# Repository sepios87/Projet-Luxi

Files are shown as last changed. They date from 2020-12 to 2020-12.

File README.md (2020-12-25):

# Projet-Luxi 💡

https://youtu.be/BHOKpEK1EPY

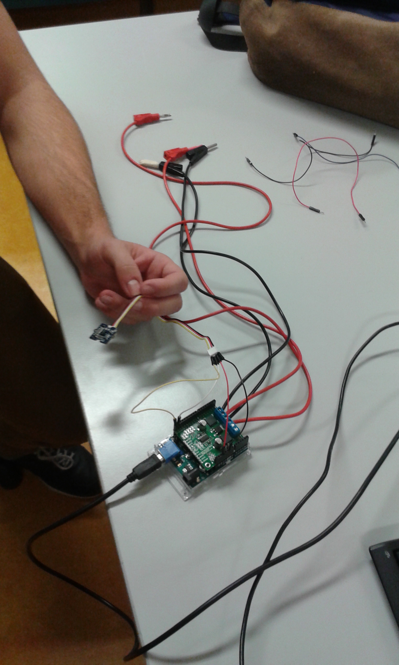
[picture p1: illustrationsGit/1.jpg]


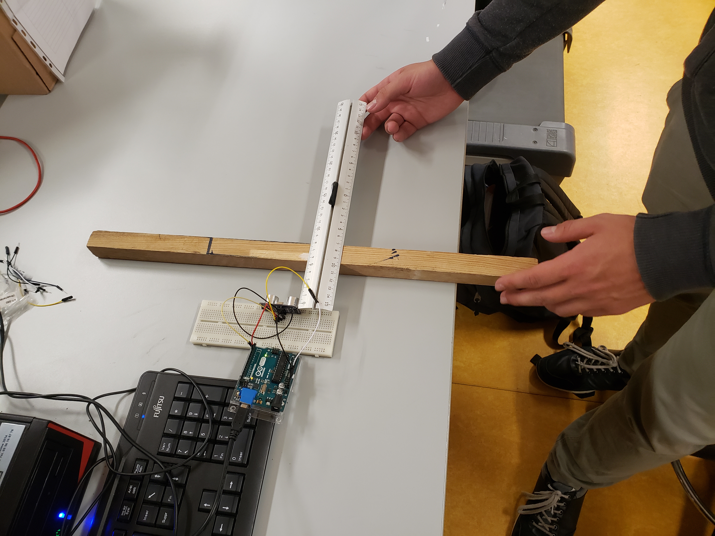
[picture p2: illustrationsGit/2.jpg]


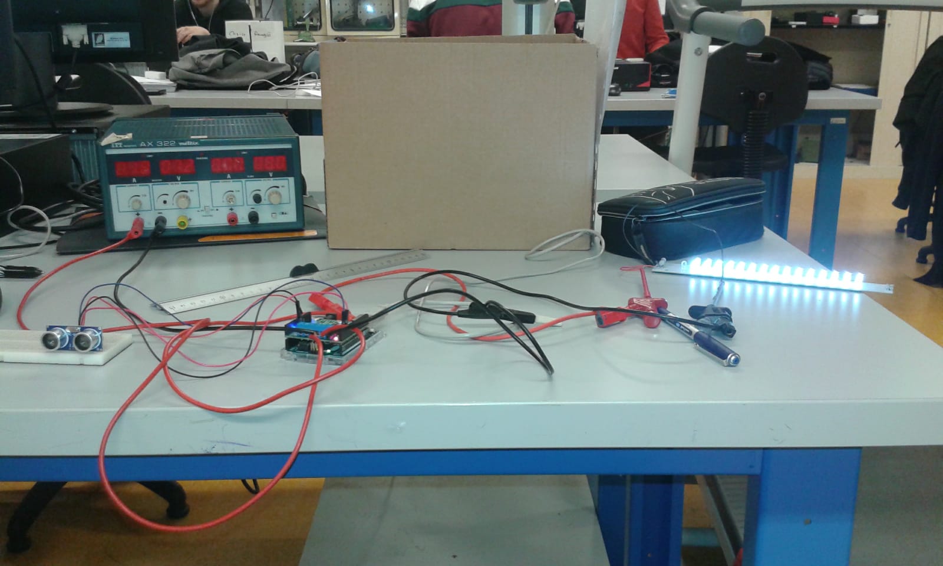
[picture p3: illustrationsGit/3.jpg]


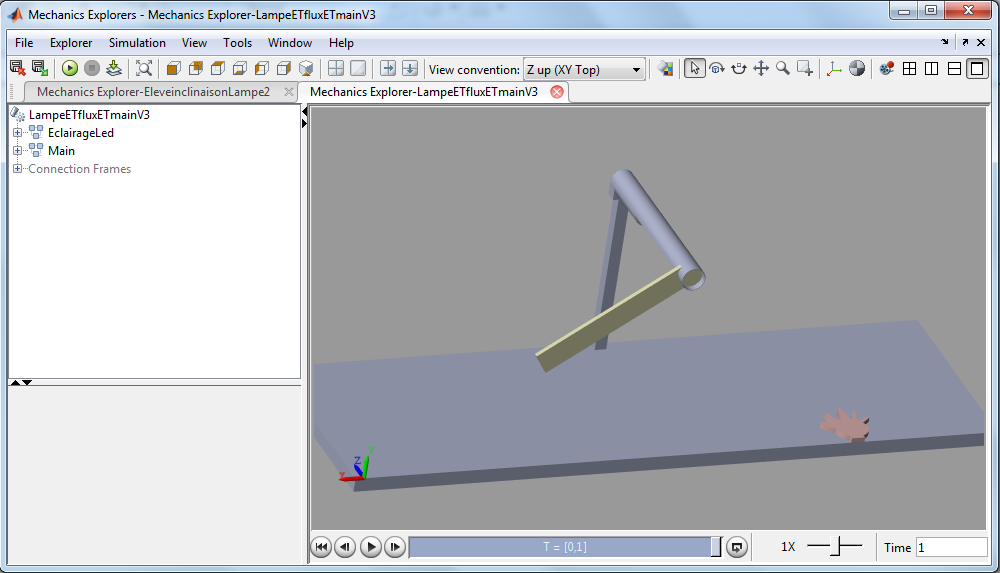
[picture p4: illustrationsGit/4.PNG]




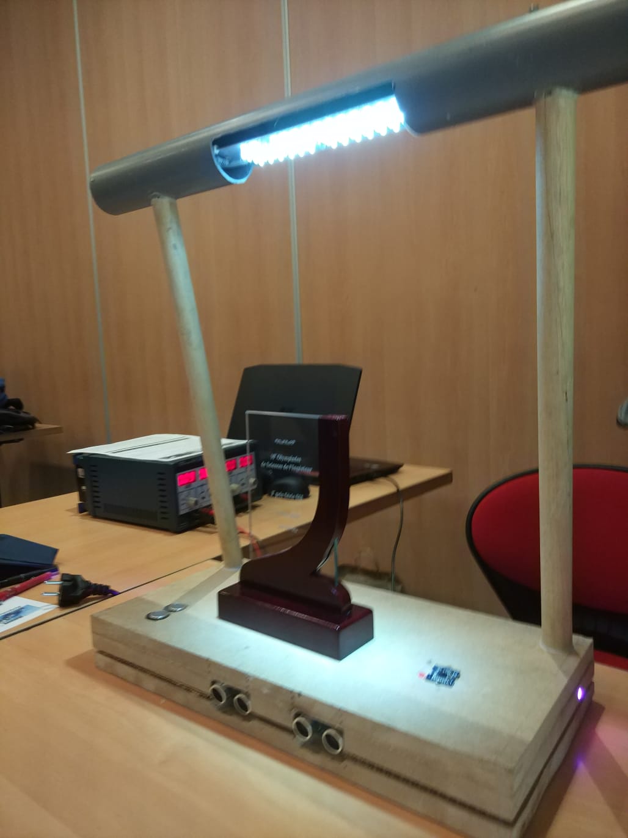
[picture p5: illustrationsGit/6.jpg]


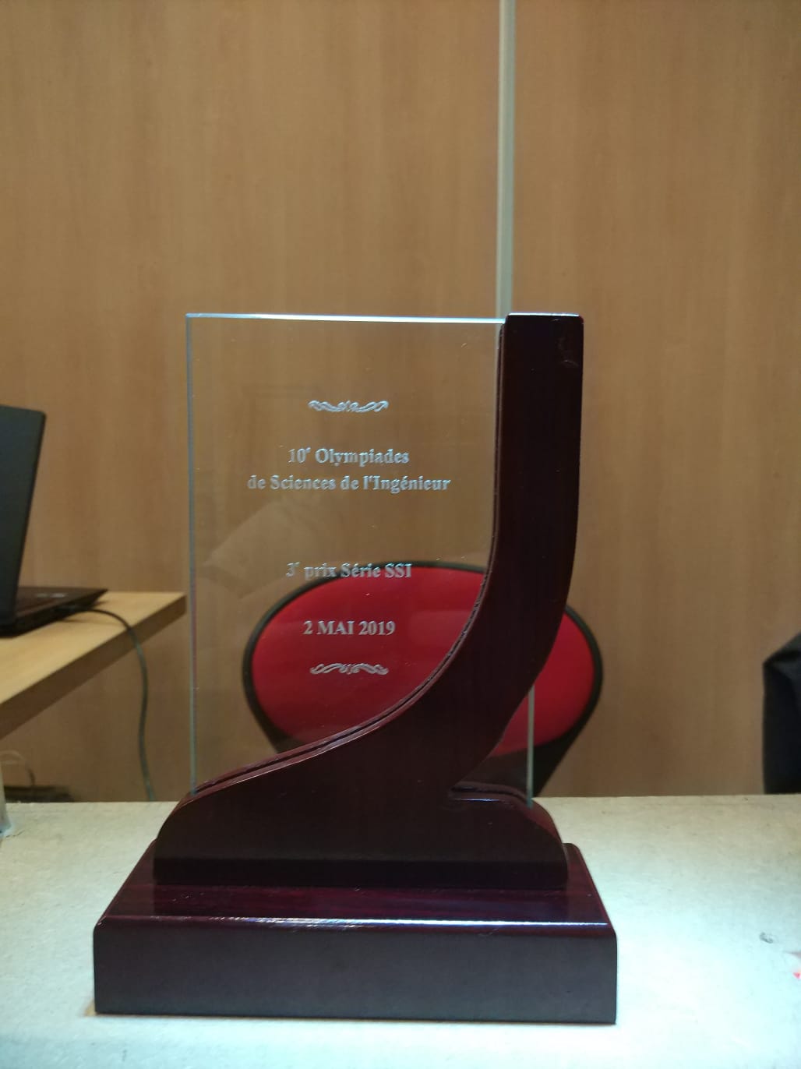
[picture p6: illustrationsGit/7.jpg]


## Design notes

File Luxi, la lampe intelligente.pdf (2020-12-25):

# Luxi, la lampe intelligente

Détection des mouvements
Candidat C

3-8

# Sommaire

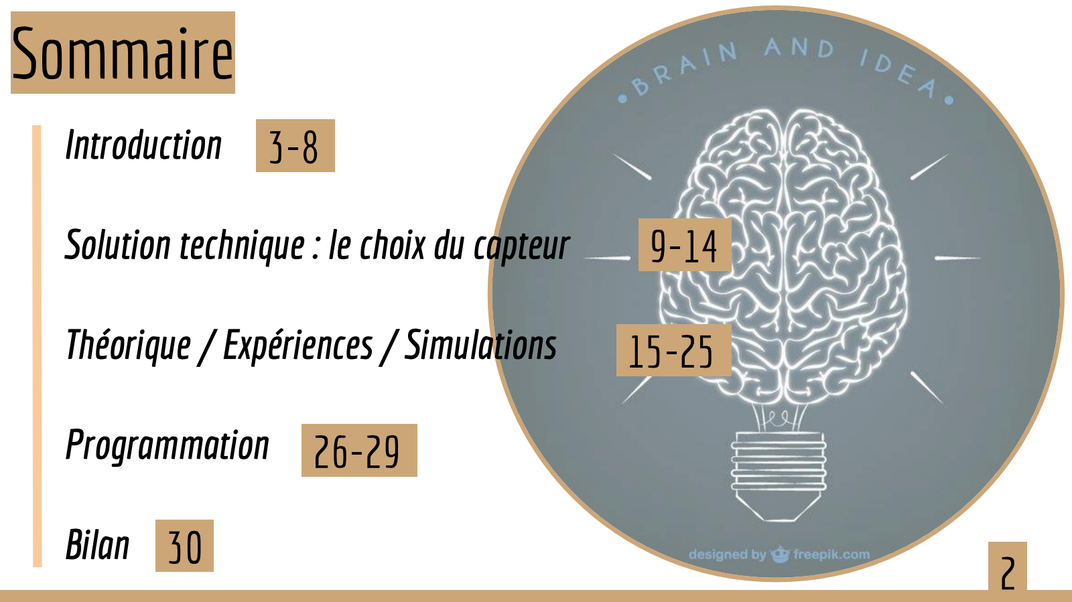
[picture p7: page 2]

2

Introduction

Solution technique : le choix du capteur

Théorique / Expériences / Simulations

Programmation

Bilan

9-14

15-25

26-29

30

# Luxi : la genèse

3

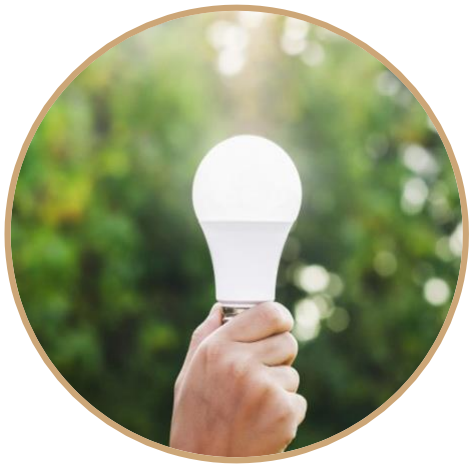
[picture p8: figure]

# Libérer l’utilisateur de la gestion de la lumière

# Pourquoi Luxi ?

4

# Des conditions toujours optimales de lumière Stimuler les activités de l’utilisateur

# Contraintes SysML

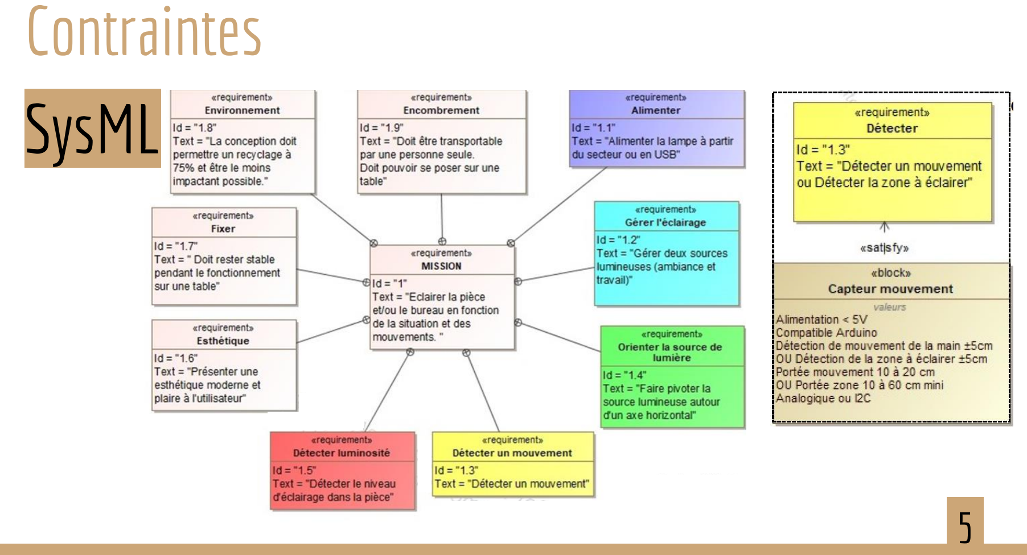
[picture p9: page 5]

5

# ANALYSE DU BESOIN

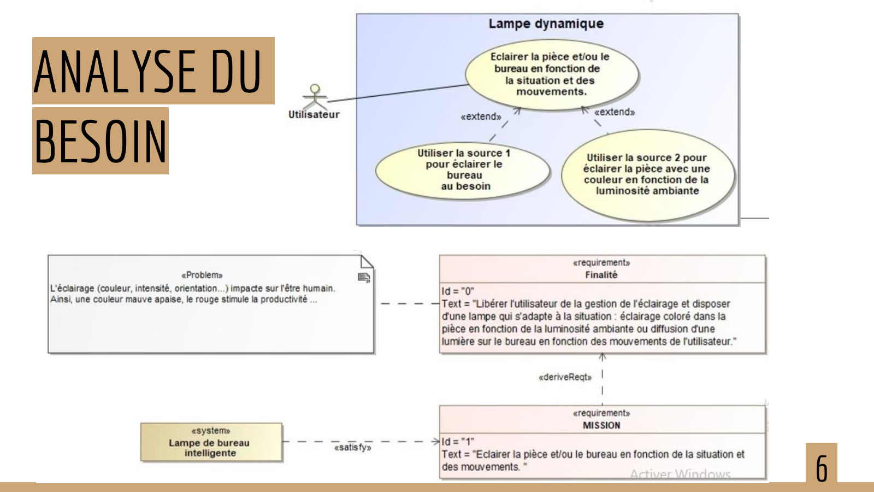
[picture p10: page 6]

6

# Chaîne d’information et d’énergie

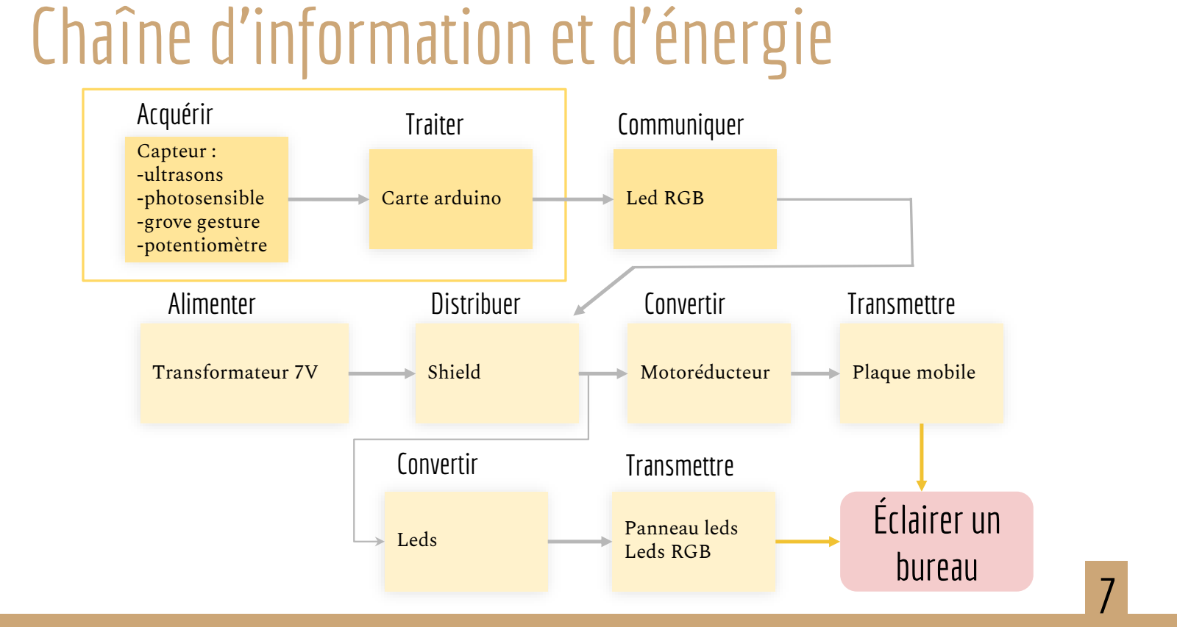
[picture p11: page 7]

Capteur :
-ultrasons
-photosensible
-grove gesture
-potentiomètre

Shield

Leds

Transformateur 7V | Motoréducteur
Carte arduino | Led RGB

Panneau leds
Leds RGB

Acquérir

Alimenter

Traiter | Communiquer
Distribuer | Convertir

Plaque mobile

Transmettre

Convertir | Transmettre
Éclairer un
bureau 7

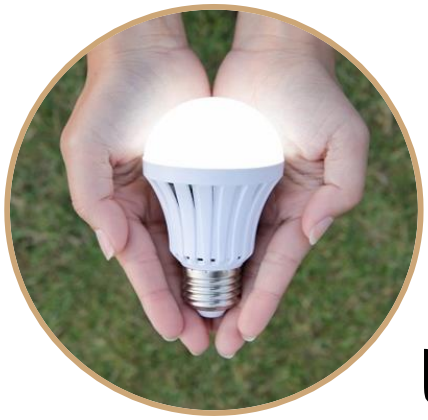
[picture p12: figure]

Utiliser un ordinateur | Ecrire | Lire

# Utilisateur

120cm

Bureau | 80cm

8

### (INRS)

# Mes missions pour ce projet

### Récupérer une distance pour orienter le flux lumineux

### Connaître les actions de l’utilisateur pour adapter les couleurs

### Faire varier l’intensité lumineuse en manuel

9

# Solution technique : le choix du capteur

10

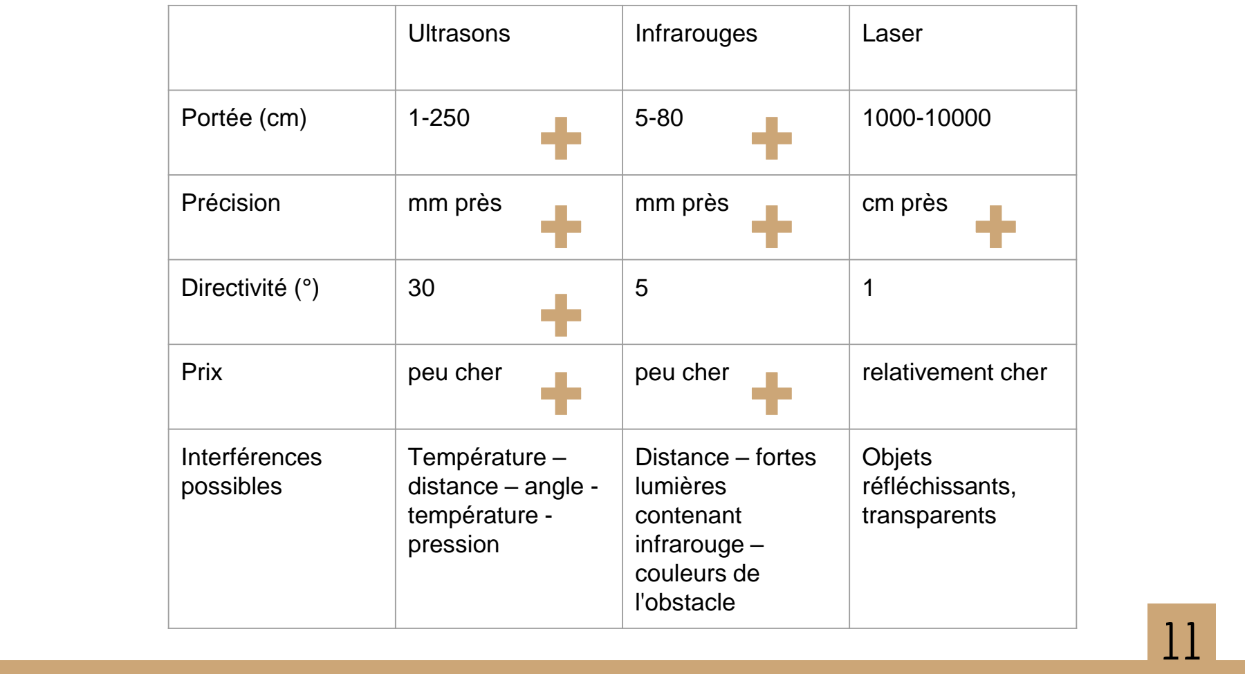
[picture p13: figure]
Ultrasons; Infrarouges; Laser; Portée (cm); Précision; mm près; cm près; Directivité (°); Interférences possibles; Température – distance – angle - température - pression; Distance – fortes lumières contenant infrarouge – couleurs de l'obstacle; Objets réfléchissants, transparents

Prix | peu cher | peu cher | relativement cher

Ultrasons

Sons Audibles

Infrasons

Fréquence d’émission du
capteur

# Inconvénient

Sensibilité de certains
chiens à cette
fréquence d’environ
40KHz
12

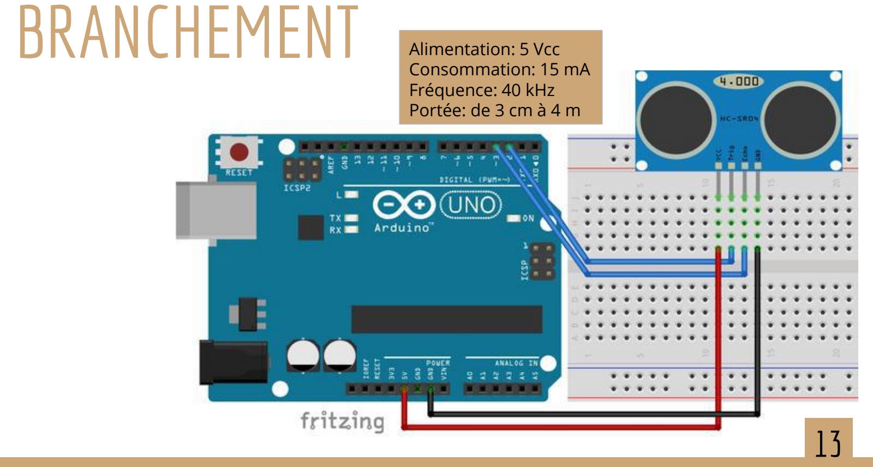
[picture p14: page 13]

BRANCHEMENT Alimentation: 5 Vcc

Consommation: 15 mA
Fréquence: 40 kHz
Portée: de 3 cm à 4 m

13

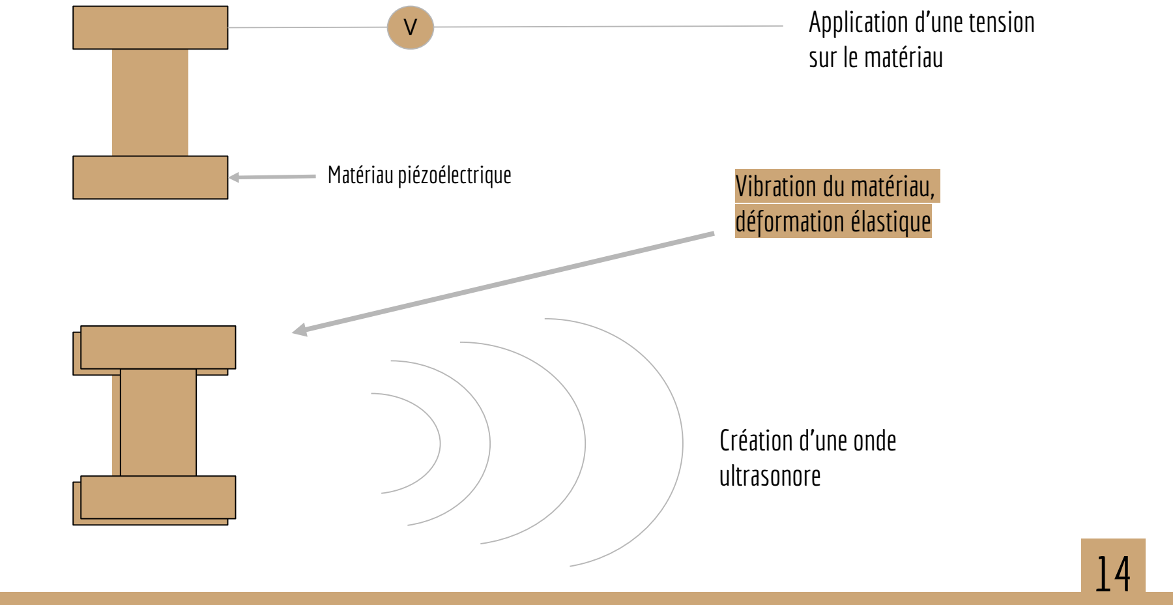
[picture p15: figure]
Application d'une tension sur le matériau; Matériau piézoélectrique; Vibration du matériau,; déformation élastique; Création d'une onde ultrasonore
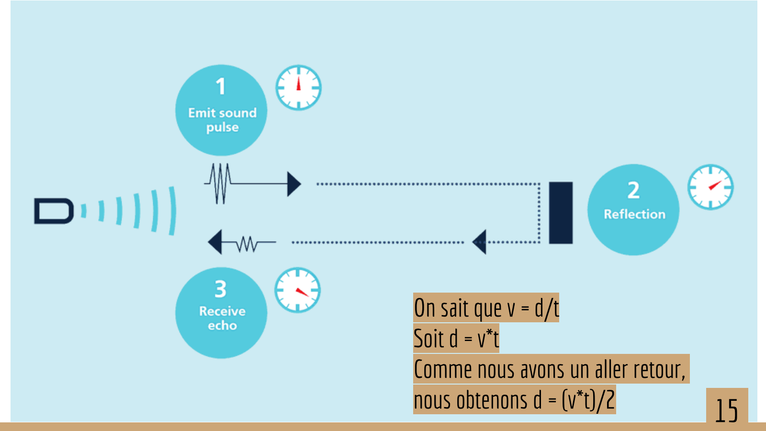
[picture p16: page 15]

On sait que v = d/t
Soit d = v*t
Comme nous avons un aller retour,
nous obtenons d = (v*t)/2 | 15

# Théorie, expériences et simulations

16

# racine(1,4*R*T)

V : vitesse du son ou de l'ultrason dans l'air (m/s)

T : température de l'air (K)

R : constante spécifique de l'air ( 281,8 Joules/Kg )

1,4 : masse volumique de l'air

V = racine(1,4*(18+273,15)*281,8) = 338,54m/s

V =

17

* température idéale d’une chambre 18°

*

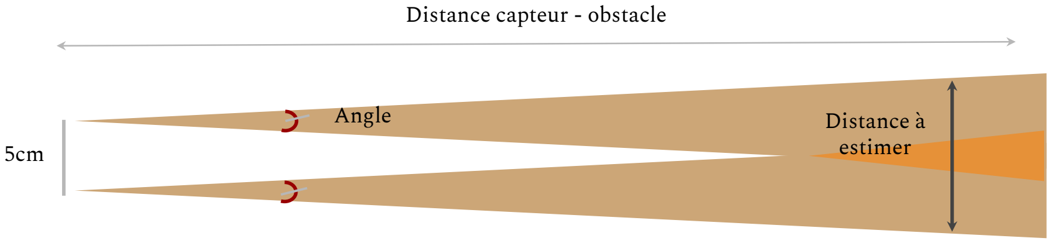
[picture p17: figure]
Angle; Distance capteur - obstacle; Distance à estimer

2d * tan(angle/2) + 5

(d.tan(angle/2).4) - (2⋅(d-(2.5/tan(angle/2))*tan(angle/2)))

Formule pour la distance cherchée pour les deux cônes avec ajustement lors du croisement

## THÉORIQUE (principe général)

(d.tan(angle/2).4) - (2d*tan(angle/2)-5)

THÉORIQUE
Angle/ Distance | 10 | 20 | 30 | 40 | 50 | 60 | 80 | 100 | 200
15 | 7.5 | 9.9 | 12.4 | 14.1 | 17.2 | 19.7 | 24.6 | 29.5 | 54.1

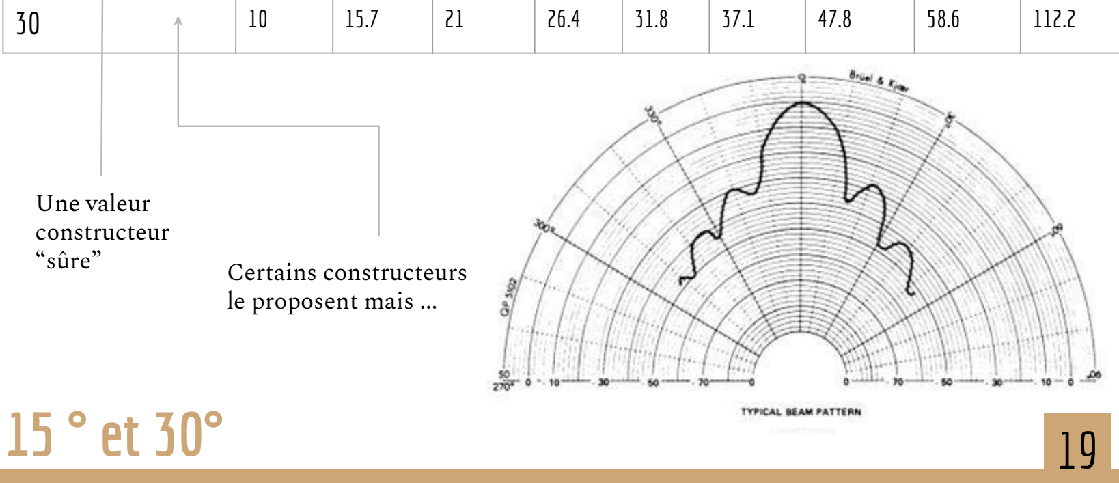
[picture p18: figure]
Une valeur constructeur; “sûre”; Certains constructeurs; le proposent mais ...
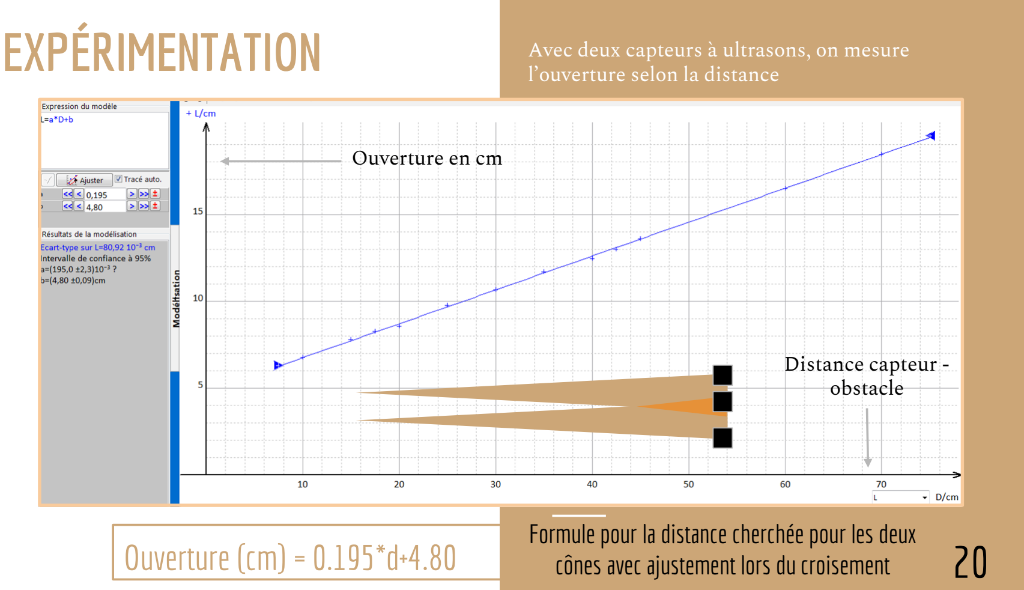
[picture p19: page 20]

EXPÉRIMENTATION | Avec deux capteurs à ultrasons, on mesure l’ouverture selon la distance

Ouverture en cm

Distance capteur -
obstacle
Ouverture (cm) = 0.195*d+4.80 | 20

Formule pour la distance cherchée pour les deux cônes avec ajustement lors du croisement

E
C
A
R
T

Ecarts “moyens et extrêmes” On peut réaliser un écart pour une valeur utilisateur moyenne (30cm) et maximale (70cm)

Théorique

2*30*tan(15/2)+5 = 12.89cm 2*70*tan(15/2)+5 = 23.43cm

Expérimentale

0.195*30+4.80 = 10.65cm
0.195*60+4.80 = 18.45cm

Ecart relatif (%) : (|théorique-

expérimentale|*100)/théorique
E30cm = 17.37%
E60cm = 21.25%
21

>10%

Expérimentale : Ouverture (cm) = 0.195*d+4.80

Théorique : 2d*tan(angle/2)+5

E
C
A
R
T

# Plus proche de 11° que de 15° ?

## Théorique

2*30*tan(11/2)+5 = 10.77cm 2*70*tan(11/2)+5 = 18.48cm

## Expérimentale

0.195*30+4.80 = 10.65cm
0.195*70+4.80 = 18.45cm

Ecart relatif (%) : (|théorique-

expérimentale|*100)/théorique

E30cm = 1.11%
E60cm = 0.16%
22

N °2

<5%

Le

# meilleur

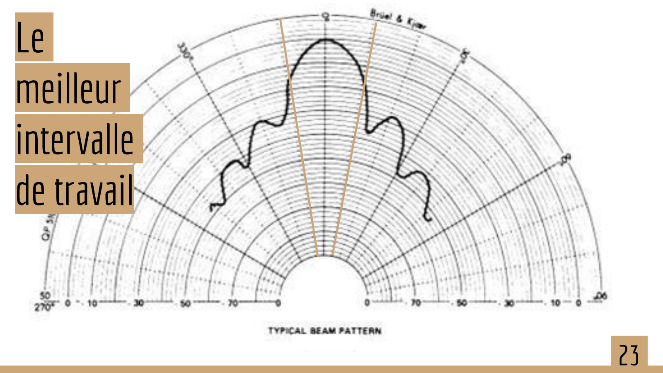
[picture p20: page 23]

23

# intervalle de travail

## SIMULATION

Capteur

Distance
main

Main

teta

Distance à
déterminer

24

Orientation panneau leds

## Réalisation d’une seconde EXPÉRIMENTATION

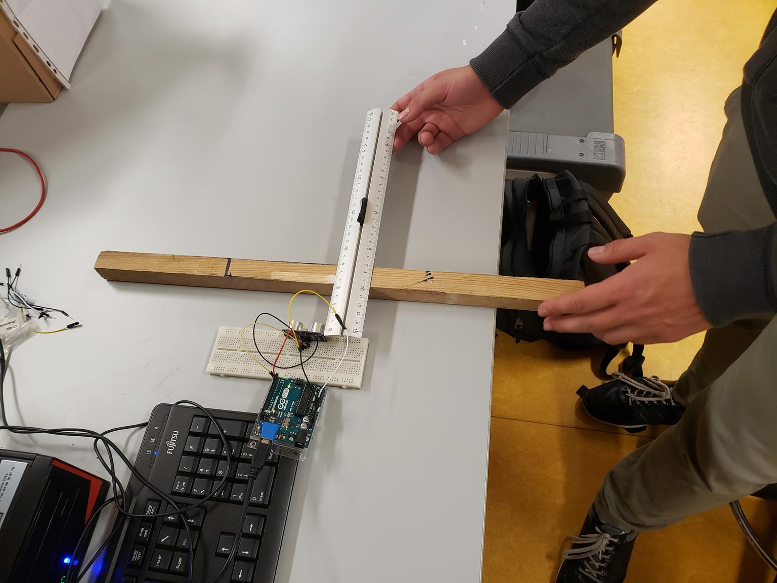
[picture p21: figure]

On admet une
erreur à cause de
l’outil de mesure
utilisé : la règle
25

## Réalisation de la 1ère EXPÉRIMENTATION

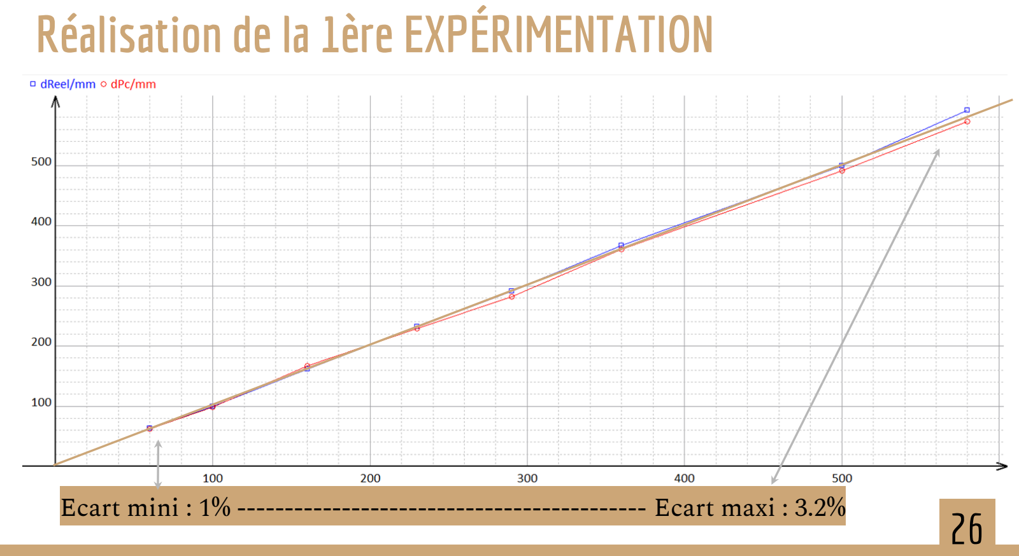
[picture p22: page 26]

Ecart mini : 1% ------------------------------------------- Ecart maxi : 3.2% 26

# Programmation

27

### define trig 2 #define trig2 11 #define trig3 13 #define echo 3 #define echo2 A4 #define echo3 A5

# A relever lors de la déclaration des broches

## Digital

### Digital ou Analogique grâce à un CAN (convertisseur analogique numérique

28

# Mode manuel

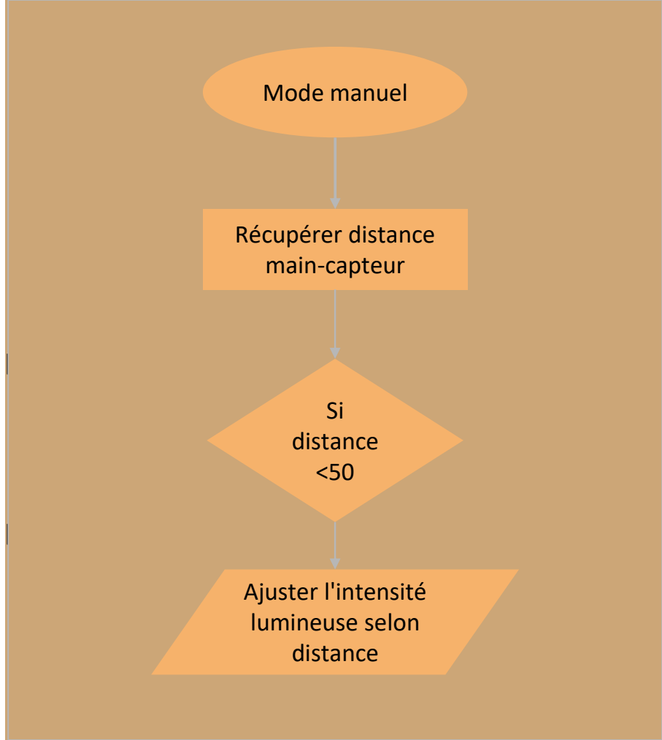
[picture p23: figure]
digitalWrite(trig, HIGH); delayMicroseconds(500); digitalWrite(trig, LOW); lecture_echo = pulseIn(echo, HIGH);; if (cm < 50){ luxDemandeUltrasons = (800*cm)/50; propoUltrasons = (255*luxDemandeUltrasons)/800;; propoPrecedent; i>propoUltrasons; i-=2){ analogWrite(PWMLED, propoPrecedent); delay(2);; propoPrecedent; i<propoUltrasons; i+=2){ analogWrite(PWMLED, propoPrecedent); delay(2); }; } delay(12); propoPrecedent = propoUltrasons;; Mode manuel; Récupérer distance main-capteur; Si distance <50; Ajuster l'intensité lumineuse selon distance

cm = ((lecture_echo * 340 /(10000))/2)-1;

if(propoPrecedent>propoUltrasons && propoPrecedent<=255) for (int i =

if(propoPrecedent<propoUltrasons && propoPrecedent<=255) for (int i =

Émettre des ultrasons

800 correspond aux lux max et 50 : la hauteur max (en cm)

Boucle pour rendre plus
progressif le changement
d'intensité lumineuse

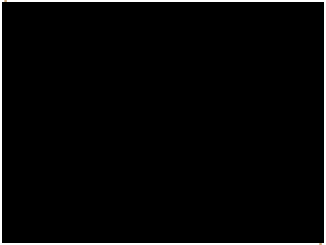
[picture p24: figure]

# Mode automatique

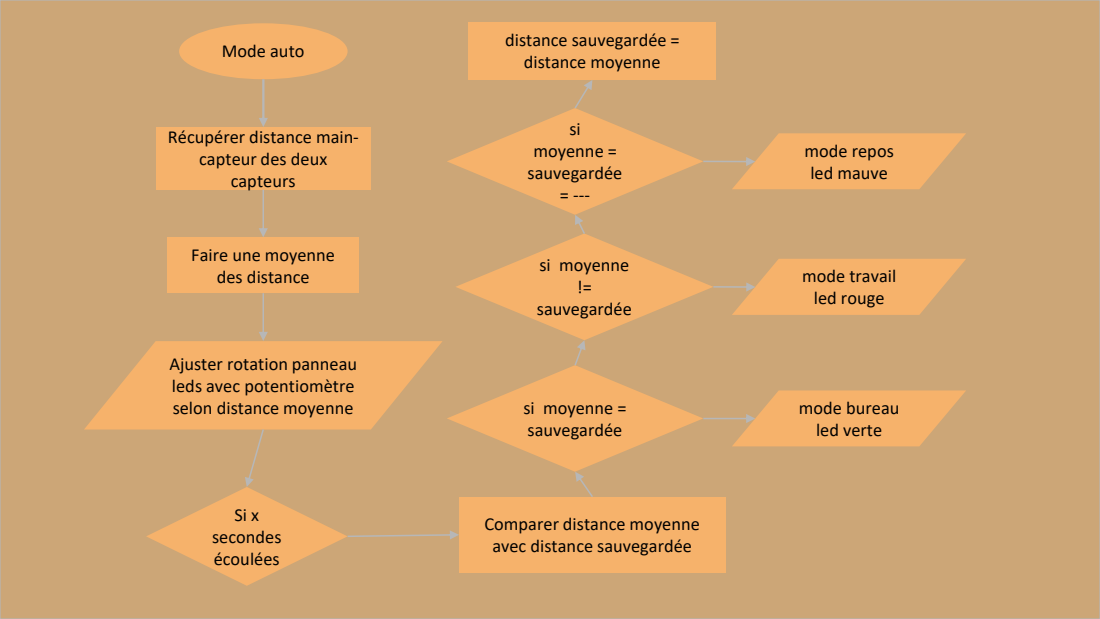
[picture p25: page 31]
((80*valPot)/1023)<cmMoy+5)){; if (((80*valPot)/1023)>cmMoy) {; Récupération des informations ultrasons; Mode auto; Si x secondes écoulées; distance moyenne; moyenne; si moyenne = sauvegardée = ---; mode bureau led verte; mode travail led rouge; mode repos led mauve

if (cm2<80 && cm3<80)cmMoy = ((cm2+cm3)/2);
distance sauvegardée = | if (cm2>80 && cm3<80)cmMoy = cm3; if (cm2<80 && cm3>80) cmMoy = cm2;

if (cm2>80 && cm3>80) cmMoy =0; if (recTps<millis()){

Récupérer distance main-
capteur des deux
capteurs

recTps= millis()+10000; //delay de 10s
if (saveCm+100<cmMoy && saveCm-100>cmMoy && cmMoy!=0){
displayColor(tableauCouleur[2]); //mode pc
} else if (cmMoy == saveCm == 0){
displayColor(tableauCouleur[5]); //mode repos
saveCm = cmMoy;

Faire une moyenne
des distance

sauvegardée
valPot = analogRead(pinPot); //pos de base du potentiometre = 500
if (cmMoy!=0){
si moyenne =

Simulation timer détecté
avec un délai de 10s

Ajuster rotation panneau
leds avec potentiomètre
selon distance moyenne
grâce aux ultrasons

if (!(((80*valPot)/1023)>cmMoy-5 &&

Gestion du potentiomètre

analogWrite(PWMMot, 240);
while(((80*valPot)/1023) != cmMoy){
digitalWrite(DIRMot, HIGH); //a changer si mauvais sens
} else {
digitalWrite(DIRMot, LOW); //a changer si mauvais sens

Comparer distance moyenne
avec distance sauvegardée

# Conclusion

32

# ON RÉCAPITULE

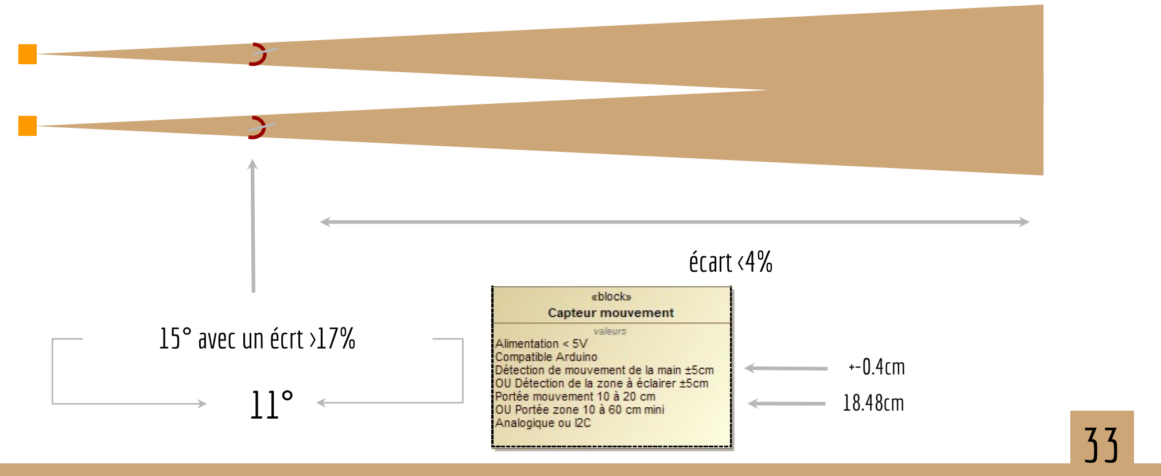
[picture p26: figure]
15° avec un écrt >17% 11°; écart <4%

34

# Sur le travail d’équipe

# Sur l’apprentissage personnel

# Un projet qui pourrait être encore amélioré

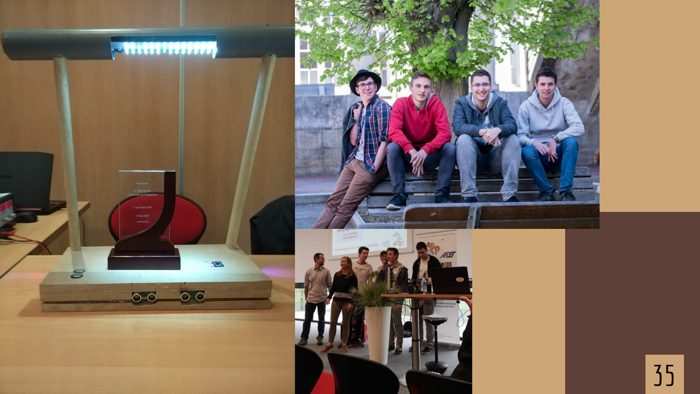
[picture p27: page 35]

35

# Partie complémentaire

36

# Pourquoi des ultrasons et non des infrasons ?

37

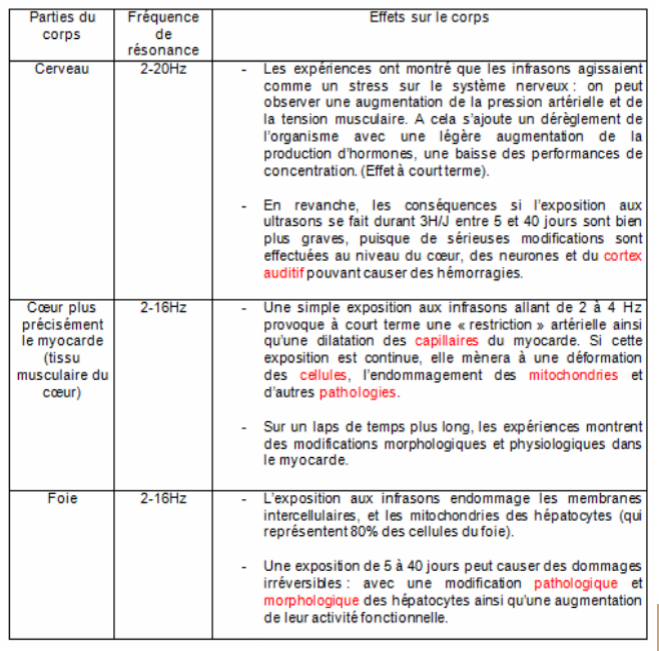
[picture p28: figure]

# En plus de pénétrer et transpercer la matière :

38

# Des interférences

39

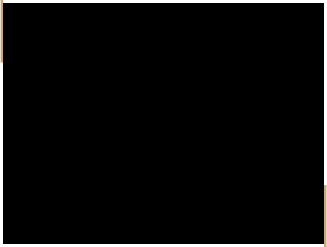
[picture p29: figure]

# Possibilité de diffracter les ultrasons ?

41

# Une possible solution pour augmenter le champ d’action du capteur

42

# Grove Gesture

43

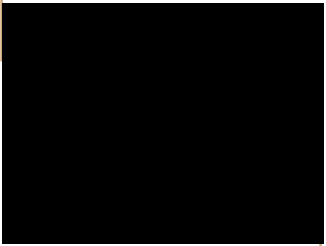
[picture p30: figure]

# -FIN-

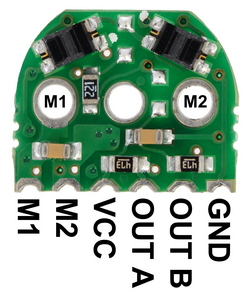
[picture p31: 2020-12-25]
MatlabLampeI/encodeurpololu.png

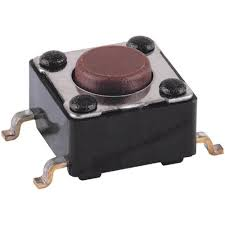
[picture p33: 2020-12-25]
MatlabLampeI/bp.png

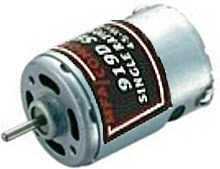
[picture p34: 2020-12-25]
MatlabLampeI/moteur2.jpg

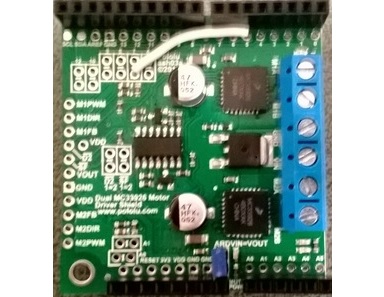
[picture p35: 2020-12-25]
MatlabLampeI/ShieldMC33926.jpg

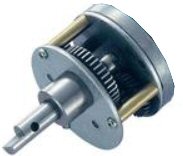
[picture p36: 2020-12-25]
MatlabLampeI/reducteur2.jpg

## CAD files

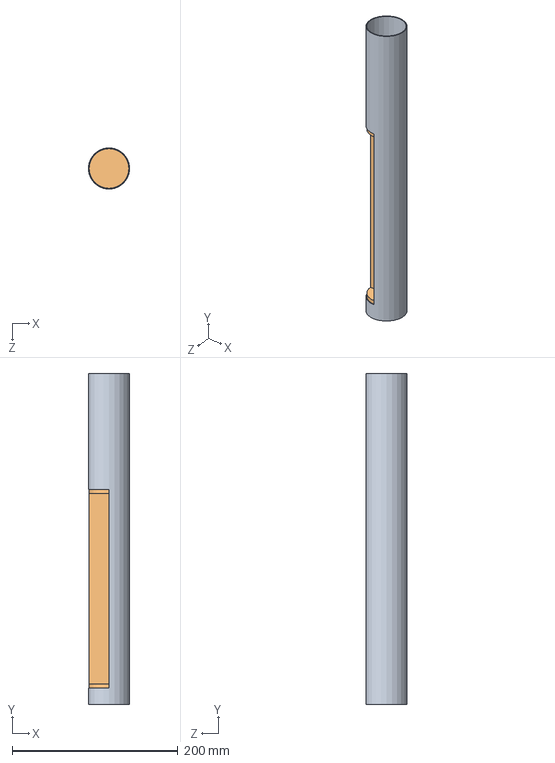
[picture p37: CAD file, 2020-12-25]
MatlabLampeI/sw/Assemblage1.SLDASM
50.0 x 400.0 x 50.0 mm
abatjour
LED

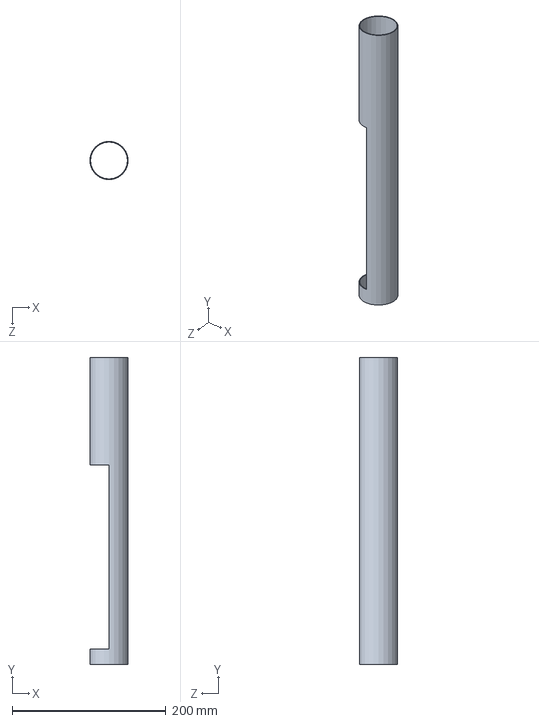
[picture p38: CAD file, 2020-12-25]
MatlabLampeI/sw/abatjour.SLDPRT
50.0 x 400.0 x 50.0 mm

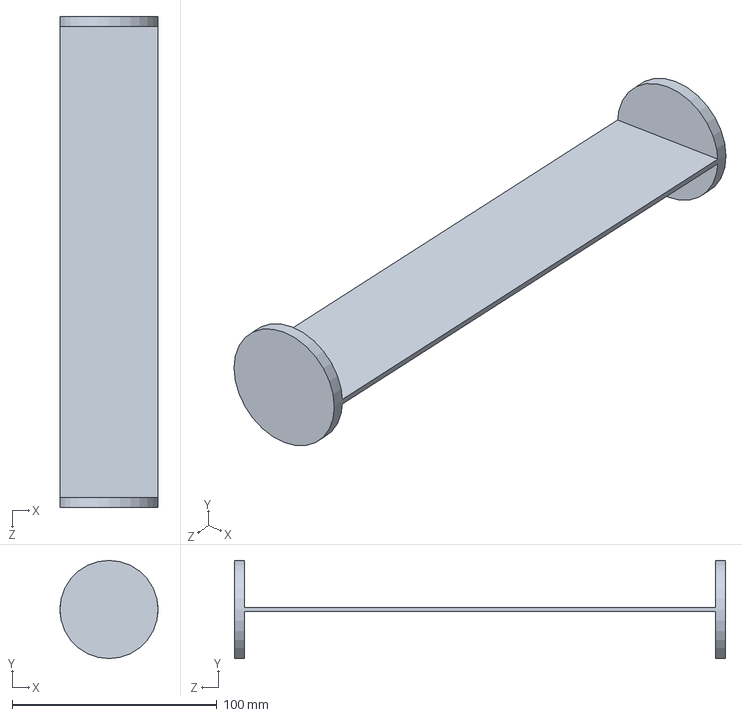
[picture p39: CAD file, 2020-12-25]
MatlabLampeI/sw/LED.SLDPRT
48.0 x 48.0 x 240.0 mm

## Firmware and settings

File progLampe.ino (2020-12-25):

#include <Wire.h>
#include "paj7620.h"
#define ActiveShield 4
#define PWMLED 9
#define DIRLed 7 //voir si necessaire
#define PWMMot 10
#define DIRMot 8
#define trig 23
int trig2 = 51; 
int trig3  = 47;
#define echo 25
int echo2 = 53;
int echo3 = 49;
#define pinPhoto A9
#define pinPot A8
#define PIN_LED_R 45
#define PIN_LED_G 43
#define PIN_LED_B 41
#define PIN_LED_R2 27
#define PIN_LED_G2 29
#define PIN_LED_B2 31

byte tableauCouleur[8] = {0b000, 0b100, 0b010, 0b001, 0b101, 0b011, 0b110, 0b111};
byte selecColor = 1;
long lecture_echo, lecture_echo2, lecture_echo3, recTps= 0;
short formuleSensib, sensorValueSensib, luxProdSensib, propoLuxSensib, del, cm, cm2, cm3, cmMoy = 0, valPot, saveCm = 0;
short propoPrecedent = 125, propoLuxPrecedent = 125;
double propoUltrasons, luxDemandeUltrasons;
boolean marche = false;
boolean manu = true;
boolean changeColor = false;
boolean delaiMouvement = false;
long tpsSave = 0;
int aChangerPot = 340;


void setup()
{
      uint8_t error = 0;
  pinMode(ActiveShield, OUTPUT); 
  pinMode(PWMLED, OUTPUT); 
  pinMode(DIRLed,OUTPUT);
  pinMode(DIRMot,OUTPUT);
  digitalWrite(DIRMot,HIGH);
  digitalWrite(DIRLed,HIGH);  
  pinMode(echo, INPUT);
  pinMode(echo2, INPUT);
  pinMode(echo3, INPUT);
  pinMode(trig, OUTPUT);
  pinMode(trig2, OUTPUT);
  pinMode(trig3, OUTPUT);
  pinMode(PIN_LED_R, OUTPUT);
  pinMode(PIN_LED_G, OUTPUT);
  pinMode(PIN_LED_B, OUTPUT);
  pinMode(PIN_LED_R2, OUTPUT);
  pinMode(PIN_LED_G2, OUTPUT);
  pinMode(PIN_LED_B2, OUTPUT);
  displayColor(tableauCouleur[7]); //apl methode en bas
      Serial.begin(9600);
    error = paj7620Init();         
}

void loop(){
  uint8_t data = 0, data1 = 0, error;

    error = paj7620ReadReg(0x43, 1, &data);            
    if (!error) 
    {
       if (data == GES_UP_FLAG) {
  paj7620ReadReg(0x43, 1, &data);
  if(!marche){ 
    //si detection mouv,et marche n'etait pas activé passer marche en vrai
    marche = true;
    manu = true;
    analogWrite(PWMMot, 0);
     analogWrite(PWMLED, 160);
    digitalWrite(pinPhoto, HIGH);
    digitalWrite(ActiveShield,HIGH);
    Serial.println("Allumer");
    displayColor2(tableauCouleur[2]);
  } else if(marche){
    //si c t deja en marche, eteindre
    marche = false;
    manu=true;
    changeColor = false;
    analogWrite(PWMLED, 0);
    digitalWrite(pinPhoto, LOW);
    digitalWrite(trig, LOW);
    digitalWrite(trig2, LOW);
    digitalWrite(trig3, LOW);
     displayColor2(tableauCouleur[7]);
    displayColor(tableauCouleur[7]);
    Serial.println("Eteindre");
}
       }
       if (!marche){  
     valPot = analogRead(pinPot);  
      Serial.println(valPot);
     if (valPot < aChangerPot-5){
      analogWrite(PWMMot, 255);
      digitalWrite(DIRMot, LOW); //haut
    }
    if (valPot > aChangerPot){
      analogWrite(PWMMot, 255);
      digitalWrite(DIRMot, HIGH); //bas
      } 
   if (valPot >=aChangerPot-5 && valPot <=aChangerPot){
    digitalWrite(ActiveShield,LOW);
    displayColor(tableauCouleur[7]);
   }
       }
//---------Detection mouvements------
if (marche){
  switch (data) {
    case GES_RIGHT_FLAG:
  paj7620ReadReg(0x43, 1, &data);
  //Droite
 action();
    break;
    case GES_LEFT_FLAG:
  paj7620ReadReg(0x43, 1, &data);
  //Gauche
action();
    break;
    case GES_DOWN_FLAG:
      paj7620ReadReg(0x43, 1, &data);
      //bas
      if (manu && marche){
      delaiMouvement = true;
      if (!changeColor){     
         displayColor2(tableauCouleur[4]);
        Serial.println("Mode changement couleur");
        changeColor = true;
      } else if (changeColor){
         displayColor2(tableauCouleur[2]);
        changeColor = false;  
        Serial.println("Quitte changement couleur");
        }
      }
    break;
  }
  }
    }else if (error){
     Serial.println("erreur!");
      }
  //----------Mode manu------------
if (manu){
  digitalWrite(trig, HIGH);
  delayMicroseconds(500);
  digitalWrite(trig, LOW);
  lecture_echo = pulseIn(echo, HIGH);
  cm = ((lecture_echo * 340 /(10000))/2)-1; // vitesse du son ; conversion millisecondes vers secondes et conversion mètre vers centimètres // le -1 est une marge impressision
  if (cm < 35){
  //40cm max mais declaration 50cm pour etre large
  luxDemandeUltrasons = (800*cm)/45; //application sur 800lux
  propoUltrasons = (255*luxDemandeUltrasons)/800;//essayer de simplifier 
  if(propoPrecedent>propoUltrasons && propoPrecedent<=255)  for (int i = propoPrecedent; i>propoUltrasons; i-=2){ 
    analogWrite(PWMLED, propoPrecedent);
    delay(2);
  }
  if(propoPrecedent<propoUltrasons && propoPrecedent<=255)  for (int i = propoPrecedent; i<propoUltrasons; i+=2){
    analogWrite(PWMLED, propoPrecedent);
    delay(2);
  }
  }
  delay(12);
  propoPrecedent = propoUltrasons;
    }
  //----------Mode auto------------
  if (marche){
  if (!manu) {
 //-----Photoresistance
  sensorValueSensib = analogRead(pinPhoto);
  formuleSensib = pow(sensorValueSensib, 1.75);
  if (800-(formuleSensib*0.056)<800){
    propoLuxSensib = ((800-(formuleSensib*0.056))*255)/800;
  } 
  if (propoLuxSensib<0){
    propoLuxSensib = 30;
  } 
  if(propoLuxPrecedent>propoLuxSensib && propoLuxPrecedent<=255)  for (int i = propoLuxPrecedent; i>propoLuxSensib; i-=2) analogWrite(PWMLED, propoLuxPrecedent);
  if(propoLuxPrecedent<propoLuxSensib && propoLuxPrecedent<=255)  for (int i = propoLuxPrecedent; i<propoLuxSensib; i+=2) analogWrite(PWMLED,propoLuxPrecedent);
  propoLuxPrecedent = propoLuxSensib;
    //Serial.println(sensorValueSensib);
  //---------doubles capteurs
  digitalWrite(trig2, HIGH);
  delayMicroseconds(500);
  digitalWrite(trig2, LOW);
  lecture_echo2 = pulseIn(echo2, HIGH);
  cm2 = ((lecture_echo2 * 340 /(10000))/2)-1; // vitesse du son ; conversion millisecondes vers secondes et conversion mètre vers centimètres // le -1 est une marge impressision
  digitalWrite(trig3, HIGH);
  delayMicroseconds(500);
  digitalWrite(trig3, LOW);
  lecture_echo3 = pulseIn(echo3, HIGH);
  cm3 = ((lecture_echo3 * 340 /(10000))/2)-1; // vitesse du son ; conversion millisecondes vers secondes et conversion mètre vers centimètres // le -1 est une marge impressision
  if (cm2<70 && cm3<70)cmMoy = ((cm2+cm3)/2);
  if (cm2>70 && cm3<70)cmMoy = cm3;
  if (cm2<70 && cm3>70) cmMoy = cm2;
  if (cm2>70 && cm3>70) cmMoy =0;
  valPot = analogRead(pinPot);
 //-----
 if (cmMoy!=0 && tpsSave < millis()){
  if (valPot > aChangerPot-(cmMoy/2)) {
    Serial.println(valPot);
    Serial.println(cmMoy);
         analogWrite(PWMMot, 100);
         digitalWrite(DIRMot, HIGH); //haut
         }
 else if (valPot < aChangerPot-(cmMoy/2)) { //detecte valeur de base a 380
  Serial.println(valPot);
  Serial.println(cmMoy);
   analogWrite(PWMMot, 100);
   digitalWrite(DIRMot, LOW); //bas
         }
  delay(2000);
  tpsSave = millis()+8000;
 }else analogWrite(PWMMot, 0);
 //-----
  if (recTps<millis()){
    recTps= millis()+5000; //delay de 5s 100ms = 1s?
    if (cmMoy<saveCm+2 && cmMoy>saveCm-2 && cmMoy!=0){
      Serial.println("pc");
      Serial.println(cmMoy);
      displayColor(tableauCouleur[4]); //mode pc
    } else if (cmMoy == 0 && saveCm == 0){
       displayColor(tableauCouleur[1]); //mode repos
       Serial.println("repos");
       Serial.println(cmMoy);
    } else{
      displayColor(tableauCouleur[5]); //mode travail
      Serial.println("travail");
      Serial.println(cmMoy);
    }
    saveCm = cmMoy;
      }
    }
  }
}
void action(){
    delaiMouvement = true;
        if (!changeColor){  
          if (manu){
           displayColor2(tableauCouleur[3]);
            manu = false;
            Serial.println("Mode auto");
          } else if (!manu){
            displayColor2(tableauCouleur[2]);
            manu  =true;
            analogWrite(PWMMot, 0);
            digitalWrite(trig2, LOW);
            digitalWrite(trig3, LOW);
            digitalWrite(pinPhoto, LOW);
            Serial.println("Mode manu");
          }
        } else if (changeColor) {
          displayColor2(tableauCouleur[4]);
          selecColor++;
          displayColor(tableauCouleur[selecColor]);
          if (selecColor == 7) selecColor = 0;
        }
}
void displayColor(byte color) { //methode changement de couleurs
  digitalWrite(PIN_LED_R, !bitRead(color, 2));
  digitalWrite(PIN_LED_G, !bitRead(color, 1));
  digitalWrite(PIN_LED_B, !bitRead(color, 0));
}
void displayColor2(byte color) { //methode changement de couleurs
  digitalWrite(PIN_LED_R2, !bitRead(color, 2));
  digitalWrite(PIN_LED_G2, !bitRead(color, 1));
  digitalWrite(PIN_LED_B2, !bitRead(color, 0));
}
